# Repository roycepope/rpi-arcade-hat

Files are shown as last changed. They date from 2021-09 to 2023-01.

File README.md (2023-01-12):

# RPi Recalbox Arcade Control Interface Module
This is a Kicad project of a PCB design for a DIY Arcade system. The goal was to design a PCB that could be easily connected to buttons via JST connectors and the standard Raspberry Pi 40-Pin GPIO header. This is a two layer board with the Top Copper layer being the main signal layer and the bottom board being the ground plane.

## Bill of Materials
| Item | Qty |Part Number |
|---|---|---|
| JST-XH 4-Pin | 7 |S4B-XH-SM4-TB(LF)(SN) |
| IDT 40-Pin | 1 |SBH11-PBPC-D20-ST-BK  |

## PCB Render
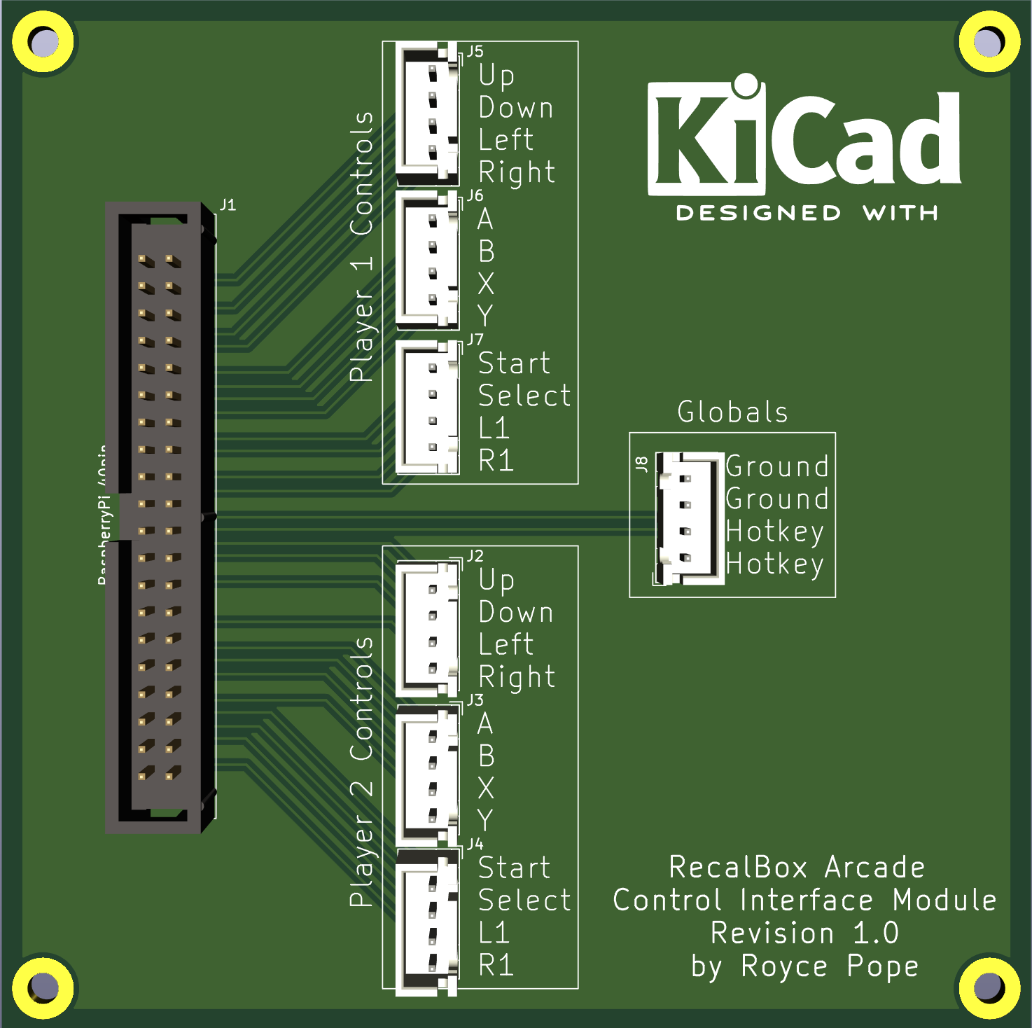
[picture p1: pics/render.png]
Board Render


## RecalBox GPIO Map
```bash
# button control: Y-, Y +, X-, X +, start, select, a, b, tr, y, x, tl
map=1 gpio=pin5,pin3,pin7,pin8,pin15,pin16,pin10,pin11,pin19,pin13,pin12,pin18
map=1,2 gpio=pin24,pin23,pin26,pin29,pin36,pin37,pin31,pin32,pin40,pin35,pin33,pin38
```

|GPIO#  |Pin# |Control |  |GPIO#  |Pin# |Control |
|---|---|---|--|---|---|---|
| 2 | 3 | Player 1 Up |  |11 | 23 | Player 2 Up |
| 3 | 5 | Player 1 Down |  | 8 | 24 | Player 2 Down |
| 4 | 7 | Player 1 Left |  | 7 | 26 | Player 2 Left |
| 14 | 8 | Player 1 Right |  | 5 | 29 | Player 2 Right |
| 15 | 10 | Player 1 A |  | 6 | 31 | Player 2 A |
| 17 | 11 | Player 1 B |  | 12 | 32 | Player 2 B |
| 18 | 12 | Player 1 X |  | 13 | 33 | Player 2 X |
| 27 | 13 | Player 1 Y |  | 19 | 35 | Player 2 Y |
| 22 | 15 | Player 1 Start |  | 16 | 36 | Player 2 Start |
| 23 | 16 | Player 1 Select(Coin)|  | 26 | 37 | Player 2 Select(Coin)|
| 24 | 18 | Player 1 L1 |  | 20 | 38 | Player 2 L1 |
| 10 | 19 | Player 1 R1 |  | 21 | 40 | Player 2 R1 |

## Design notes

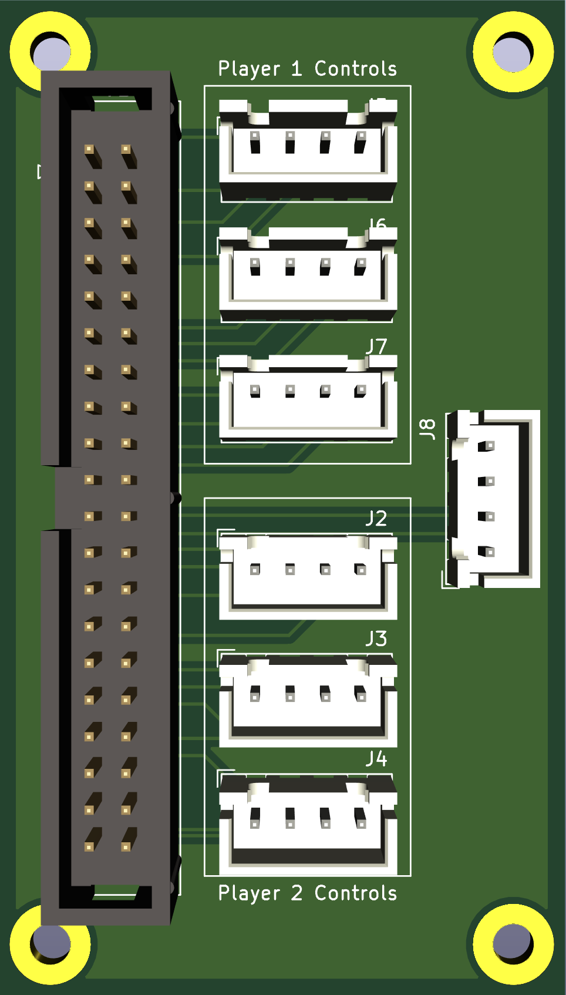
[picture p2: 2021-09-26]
pics/rpi-arcade-hat.png

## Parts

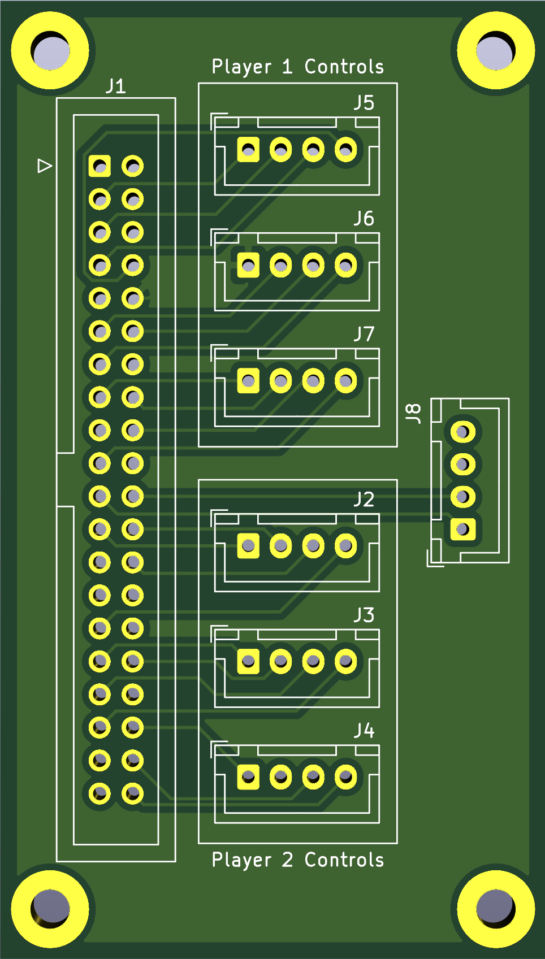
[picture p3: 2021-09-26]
pics/rpi-arcade-hat-no-components.png

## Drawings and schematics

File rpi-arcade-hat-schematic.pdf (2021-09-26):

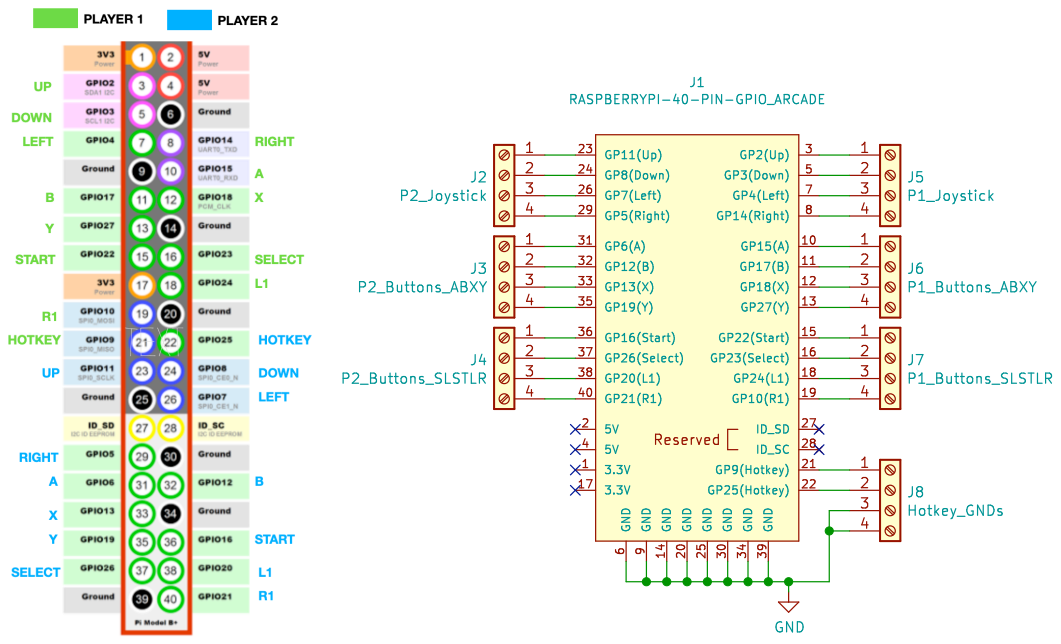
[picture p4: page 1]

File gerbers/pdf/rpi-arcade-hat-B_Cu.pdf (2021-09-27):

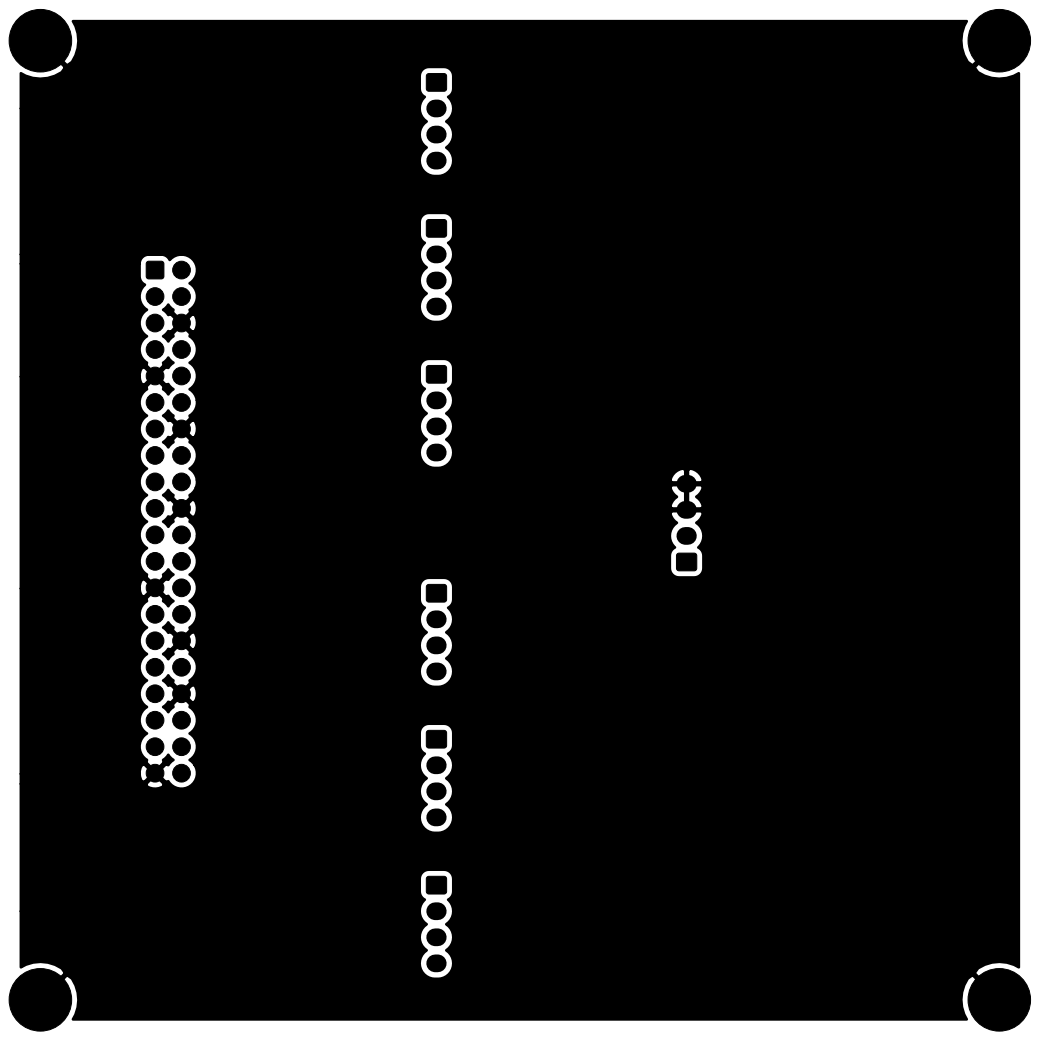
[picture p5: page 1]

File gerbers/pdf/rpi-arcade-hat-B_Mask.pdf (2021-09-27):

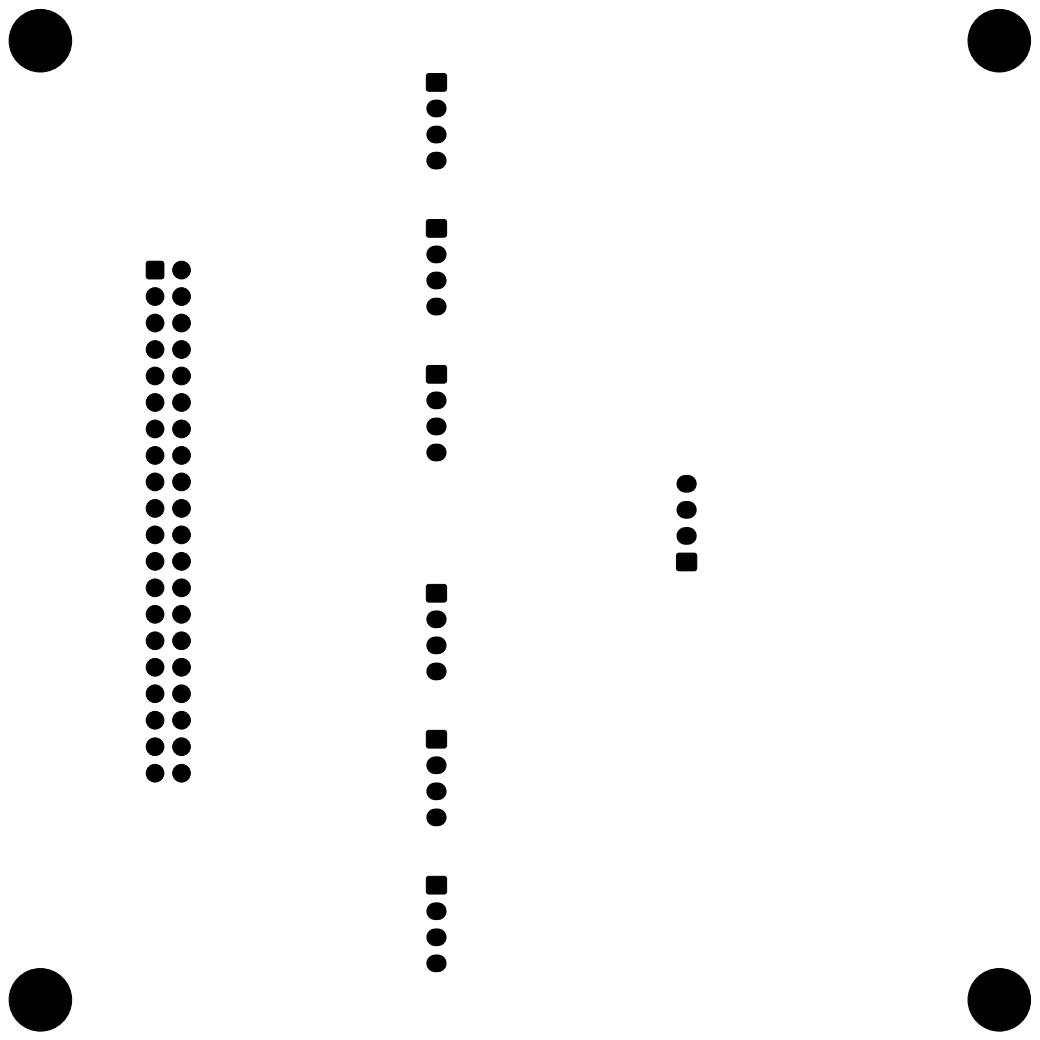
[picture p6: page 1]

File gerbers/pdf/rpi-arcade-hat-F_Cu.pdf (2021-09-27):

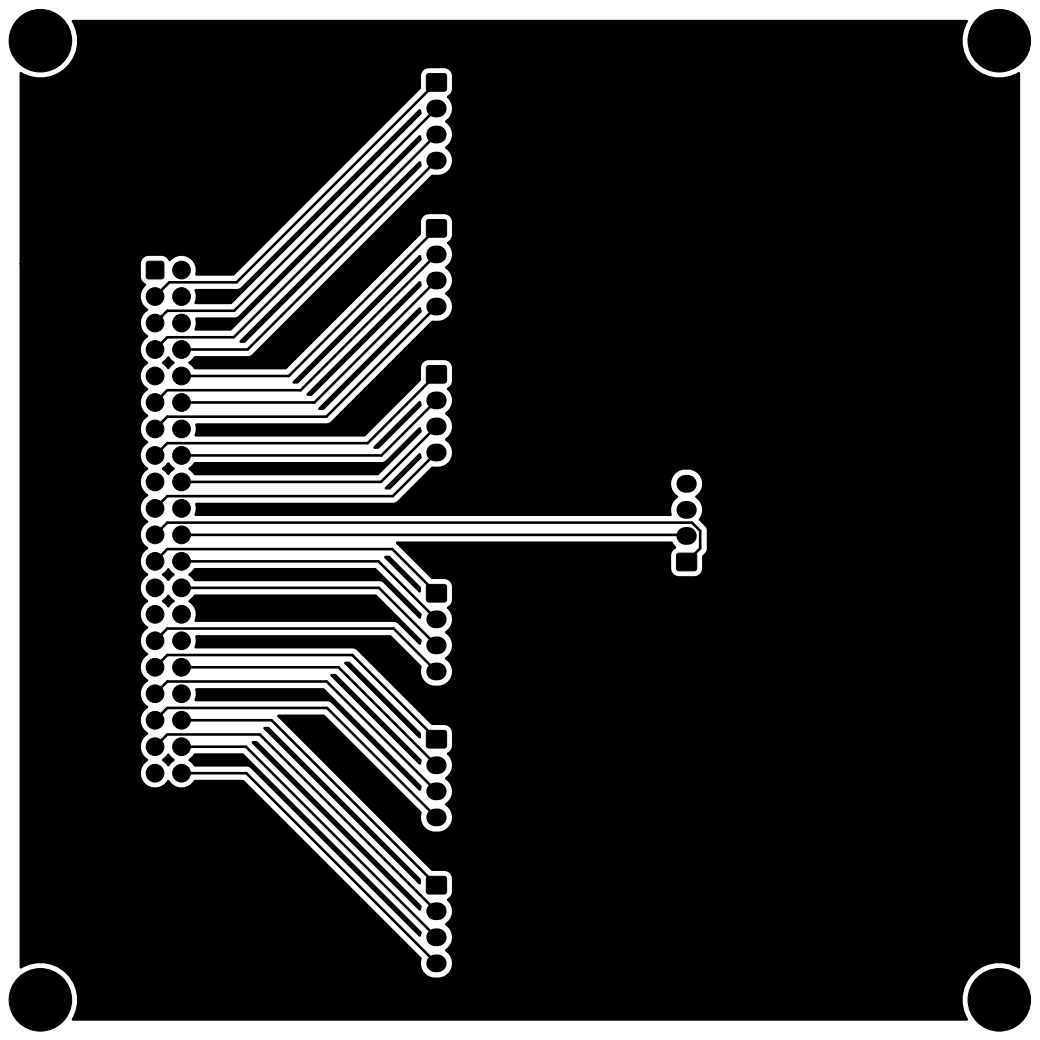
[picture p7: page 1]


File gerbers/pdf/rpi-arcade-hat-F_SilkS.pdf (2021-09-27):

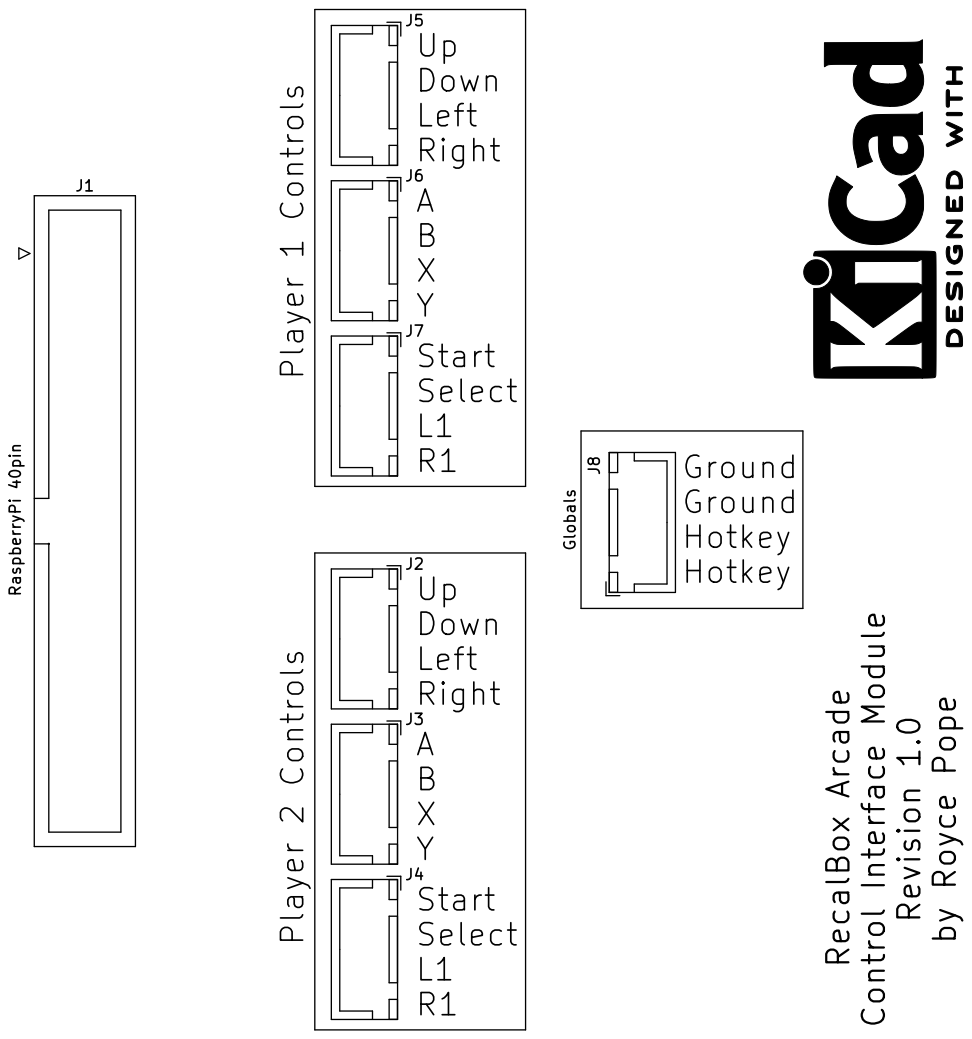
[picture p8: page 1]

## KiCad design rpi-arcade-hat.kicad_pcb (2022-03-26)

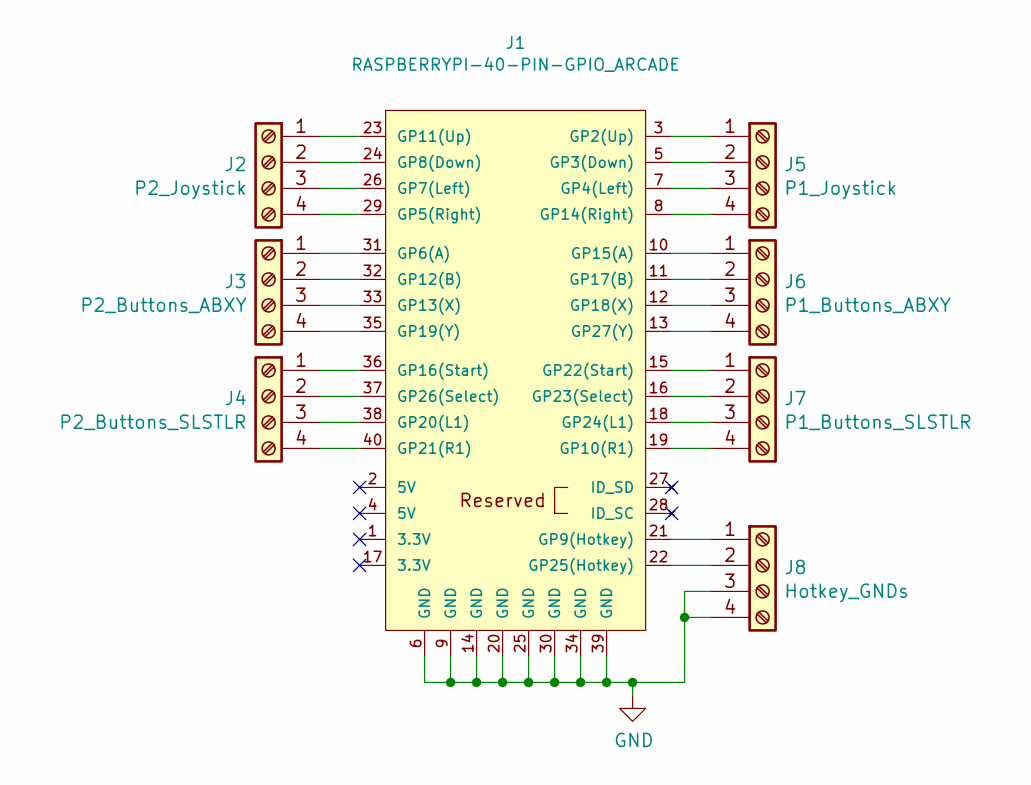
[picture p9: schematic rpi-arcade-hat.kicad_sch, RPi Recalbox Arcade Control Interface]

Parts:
J1: RASPBERRYPI-40-PIN-GPIO_ARCADE; IDC-Header_2x20_P2.54mm_Vertical
J2: P2_Joystick; JST_XH_B4B-XH-A_1x04_P2.50mm_Vertical
J3: P2_Buttons_ABXY; JST_XH_B4B-XH-A_1x04_P2.50mm_Vertical
J4: P2_Buttons_SLSTLR; JST_XH_B4B-XH-A_1x04_P2.50mm_Vertical
J5: P1_Joystick; JST_XH_B4B-XH-A_1x04_P2.50mm_Vertical
J6: P1_Buttons_ABXY; JST_XH_B4B-XH-A_1x04_P2.50mm_Vertical
J7: P1_Buttons_SLSTLR; JST_XH_B4B-XH-A_1x04_P2.50mm_Vertical
J8: Hotkey_GNDs; JST_XH_B4B-XH-A_1x04_P2.50mm_Vertical

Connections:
GND: J1.6 (GND), J1.9 (GND), J1.14 (GND), J1.20 (GND), J1.25 (GND), J1.30 (GND), J1.34 (GND), J1.39 (GND), J8.3, J8.4
unnamed: J1.3 (GP2(Up)), J5.1
unnamed: J1.5 (GP3(Down)), J5.2
unnamed: J1.7 (GP4(Left)), J5.3
unnamed: J1.8 (GP14(Right)), J5.4
unnamed: J1.10 (GP15(A)), J6.1
unnamed: J1.11 (GP17(B)), J6.2
unnamed: J1.12 (GP18(X)), J6.3
unnamed: J1.13 (GP27(Y)), J6.4
unnamed: J1.15 (GP22(Start)), J7.1
unnamed: J1.16 (GP23(Select)), J7.2
unnamed: J1.18 (GP24(L1)), J7.3
unnamed: J1.19 (GP10(R1)), J7.4
unnamed: J1.21 (GP9(Hotkey)), J8.1
unnamed: J1.22 (GP25(Hotkey)), J8.2
unnamed: J1.23 (GP11(Up)), J2.1
unnamed: J1.24 (GP8(Down)), J2.2
unnamed: J1.26 (GP7(Left)), J2.3
unnamed: J1.29 (GP5(Right)), J2.4
unnamed: J1.31 (GP6(A)), J3.1
unnamed: J1.32 (GP12(B)), J3.2
unnamed: J1.33 (GP13(X)), J3.3
unnamed: J1.35 (GP19(Y)), J3.4
unnamed: J1.36 (GP16(Start)), J4.1
unnamed: J1.37 (GP26(Select)), J4.2
unnamed: J1.38 (GP20(L1)), J4.3
unnamed: J1.40 (GP21(R1)), J4.4

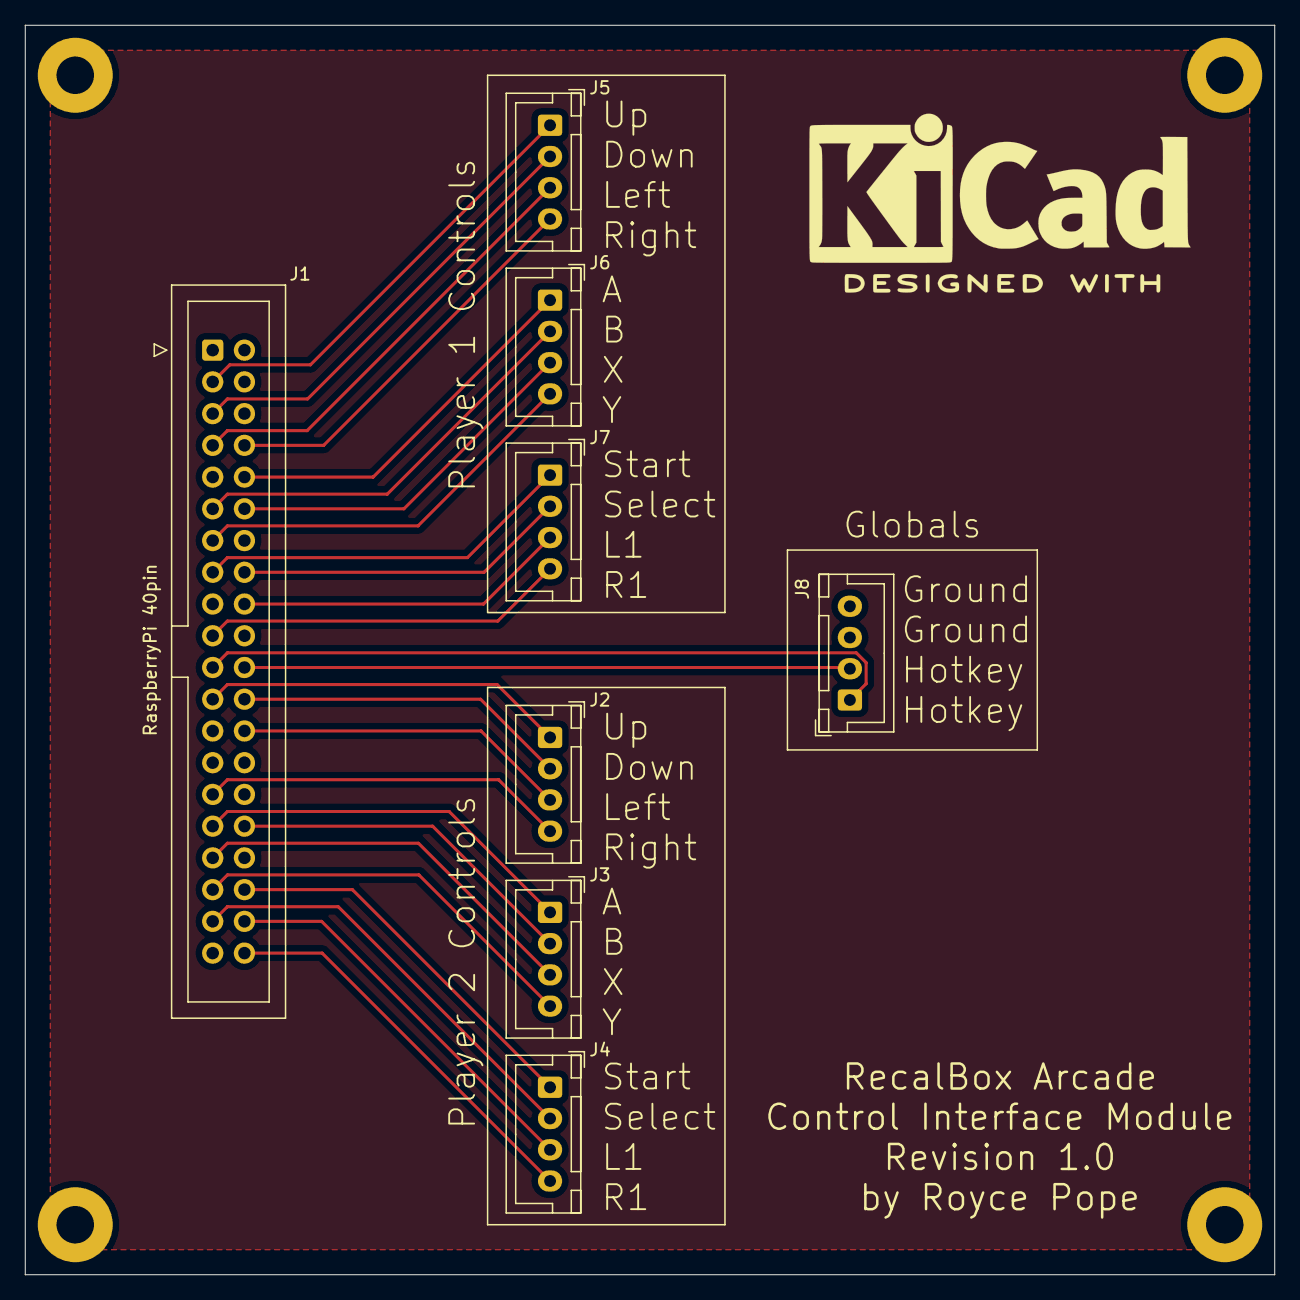
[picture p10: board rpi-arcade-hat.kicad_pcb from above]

Board: 2 copper layers, 100.0 x 100.0 mm, 8 parts (0 on the bottom side), 27 nets.

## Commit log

2021-09-26 Initial commit of the RPi Recalbox Arcade Control Interface Module KiCad project files
    [rpi-arcade-hat-B_Cu.gbr, rpi-arcade-hat-B_Mask.gbr, rpi-arcade-hat-Edge_Cuts.gbr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]
2021-09-26 Added 100mm PCBWay layout
    [rpi-arcade-hat-B_Cu.gbr, rpi-arcade-hat-B_Mask.gbr, rpi-arcade-hat-Edge_Cuts.gbr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]
2021-09-27 Update PCB render
2021-09-27 Added description and BOM
2021-09-29 Add Part numbers, modify silkscreen, remove unused layers.
    [rpi-arcade-hat.kicad_pcb]
2021-09-29 Add GPIO and Pin mapping to README
2022-03-26 Update to KiCad 6.0
    There are new file extensions for KiCad 6.0. I left the old files for backwards compatibility.
    [rpi-arcade-hat.kicad_pcb, rpi-arcade-hat.kicad_sch]
